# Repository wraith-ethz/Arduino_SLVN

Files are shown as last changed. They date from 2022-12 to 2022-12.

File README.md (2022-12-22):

# Arduino_SLVN
Board for Arduino MKRZero with various buttons / LEDs etc. to learn programming for young children

## Setup

### Assembly
 * Assemble the board according to the file `THT Assembly Drawing.pdf` in the repository under `PCB/Assembly/`
 * The 8x8 Bi-Color LED Matrix from Adafruit can be assembled according to [this link](https://learn.adafruit.com/adafruit-led-backpack/bi-color-8x8-matrix-assembly)

### Installing the Software
 * Download Arduino IDE from [here](https://www.arduino.cc/en/software) and install it
 * Configure Arduino IDE:
  * [libraries](https://docs.arduino.cc/software/ide-v2/tutorials/ide-v2-installing-a-library): install `Adafruit LED Backpack` and `Adafruit GFX` (they are used for the 8x8 matrix)
  * [boards](https://docs.arduino.cc/software/ide-v2/tutorials/ide-v2-board-manager): install `Arduino SAMD Bards` (supports the used Arduino MKRZero board / SAMD21 / ARM Cortex-M0 core)

### Arduino Blocks
 *  go to [ArduinoBlocks.com](http://www.arduinoblocks.com/), create a login

## Workflow
 * create your awesome code on ArduinoBlocks (examples are in the repository folder `/ArduinoBlocks_Examples/`)
  * Use the `MEGA 2560` as project type
  * give it a name, and start coding
 * Connect the board to the PC
 * Start Arduino IDE and create a new sketch (make sure that you have selected the MKRZero as board and the correct COM port)
 * in ArduinoBlocks, go to `Blocks->View Code`
 * Press the `Copy` button
 * Paste it in the Arduino IDE and upload the sketch
 * The Board should now do what you want
 * Enjoy :)

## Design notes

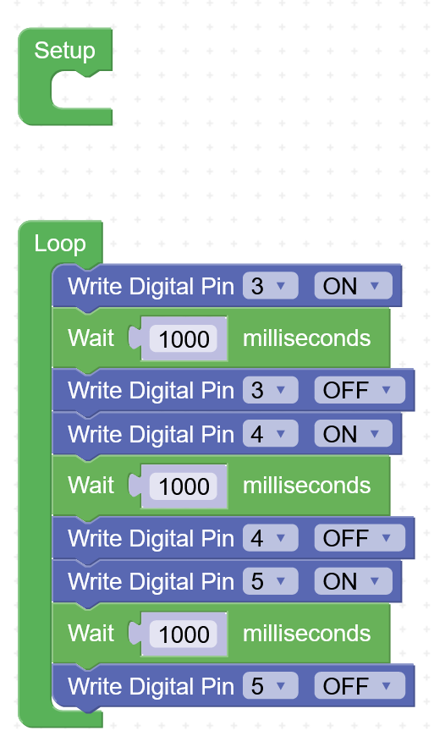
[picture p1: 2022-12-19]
ArduinoBlocks_Examples/RunningLight.png

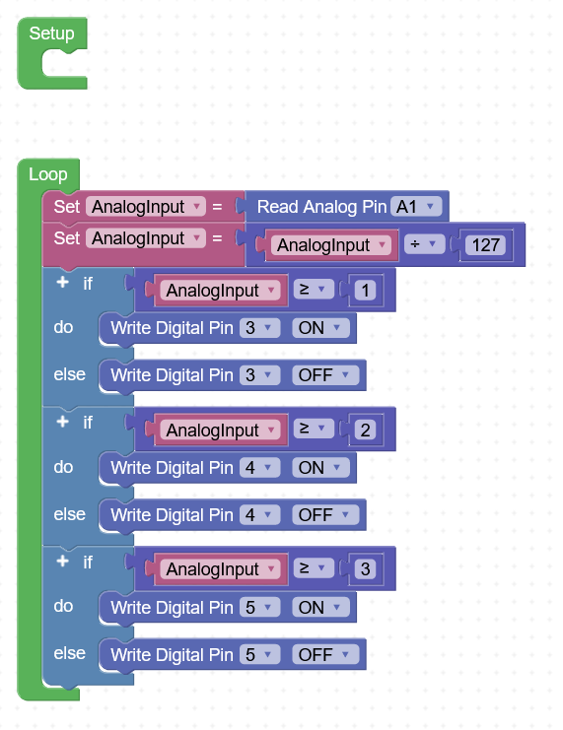
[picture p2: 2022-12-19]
ArduinoBlocks_Examples/AnalogInLED.png

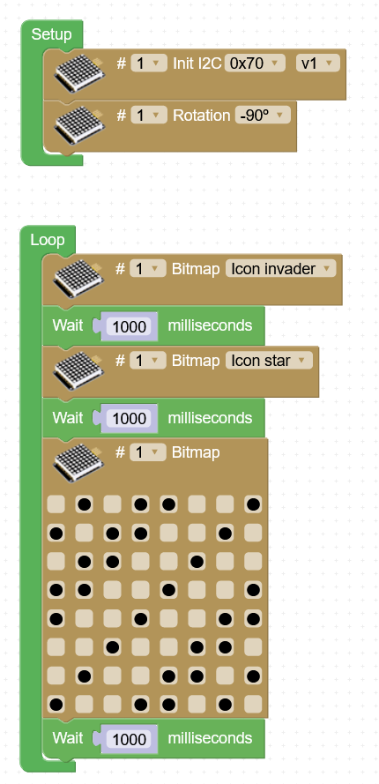
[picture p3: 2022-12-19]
ArduinoBlocks_Examples/8x8Matrix.png

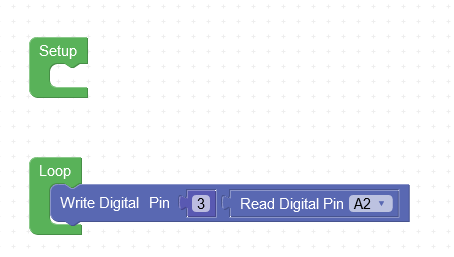
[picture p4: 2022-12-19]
ArduinoBlocks_Examples/InputSwitchToLed.png

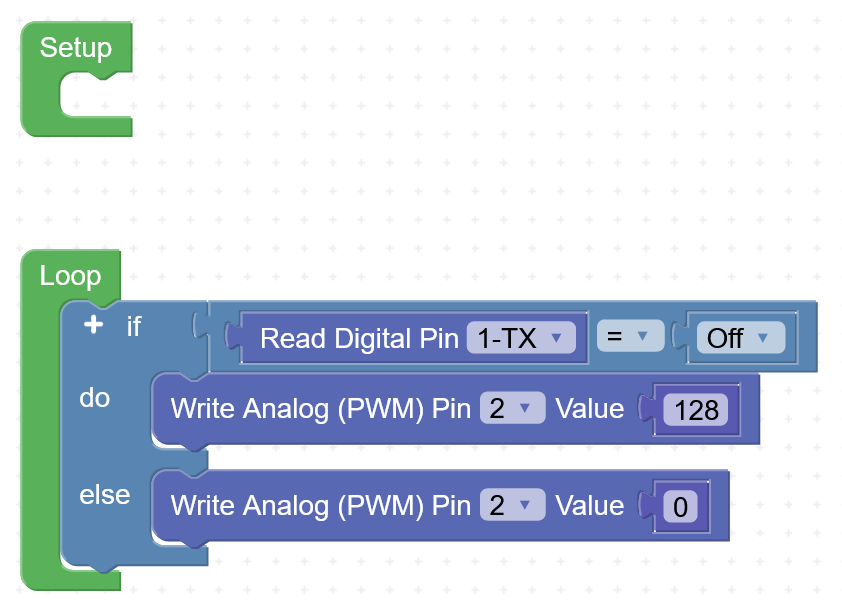
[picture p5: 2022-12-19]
ArduinoBlocks_Examples/BuzzerButton.png

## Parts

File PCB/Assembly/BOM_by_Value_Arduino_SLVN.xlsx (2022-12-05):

Designator | Quantity | Description | Manufacturer | Manufacturer Part Number | Supplier | Supplier Part Number
C1, C2, C3_0, C3_1, C3_2, C3_3, C3_4, C3_5, C3_6, C3_7 | 10 | CERCAP 1n 100V 1% NP0/C0G 0603 | KEMET | C0603C102F1GAC7867 | Digi-Key | 399-17967-1-ND
D1_0, D1_1, D1_2, D1_3, D1_4, D1_5, D1_6, D1_7 | 8 | LED RED 30mA 2V 3x3.4mm | OSRAM Opto Semiconductors Inc. | LS T676-R1S1-1-Z | Digi-Key | 475-2683-1-ND
J1, J2 | 2 | CONN Female 1x14 2.54mm Straight THT 2.54x35.6mm | Sullins Connector Solutions | PPTC141LFBN-RC | Digi-Key | S7012-ND
J3 | 1 | CONN Female 1x4 2.54mm Straight THT 2.54x10.16mm | Sullins Connector Solutions | PPTC041LFBN-RC | Digi-Key | S7002-ND
Q1_0, Q1_1, Q1_2, Q1_3, Q1_4, Q1_5, Q1_6, Q1_7, Q2, Q3 | 10 | MOSFET N 0.2A 50V SOT323 | Diodes Incorporated | BSS138W-7-F | Digi-Key | BSS138W-FDICT-ND
R1, R4_0, R4_1, R4_2, R4_3, R4_4, R4_5, R4_6, R4_7, R7_0, R7_1, R7_2, R7_3, R7_4, R7_5, R7_6, R7_7, R8, R9 | 19 | RES 10K 100mW 1% 0603 | YAEGO | RC0603FR-0710KL | Digi-Key | 311-10.0KHRCT-ND
R2, R5_0, R5_1, R5_2, R5_3, R5_4, R5_5, R5_6, R5_7, R6_0, R6_1, R6_2, R6_3, R6_4, R6_5, R6_6, R6_7 | 17 | RES 150R 100mW 1% 0603 | YAEGO | RC0603FR-07150RL | Digi-Key | 311-150HRCT-ND
R3 | 1 | POTENTIOMETER 10K 50mW 20% 11x9.7mm | Bourns Inc. | PTV09A-4020S-B103 | Digi-Key | PTV09A-4020S-B103-ND
S1 | 1 | BUTTON SPST 12V 0.05A 7.4x7.4mm | E-Switch | TL6120CF300QG | Digi-Key | EG4355CT-ND
S2_0, S2_1, S2_2, S2_3, S2_4, S2_5, S2_6, S2_7 | 8 | SWITCH SPDT 12V 0.1A 4.3x8.6mm | C&K | OS102011MS2QN1 | Digi-Key | CKN9565-ND
XTAL1 | 1 | PASSIVE PIEZO_BUZZER 12.6x7.8mm | TDK Corporation | PS1240P02BT | Digi-Key | 445-2525-1-ND

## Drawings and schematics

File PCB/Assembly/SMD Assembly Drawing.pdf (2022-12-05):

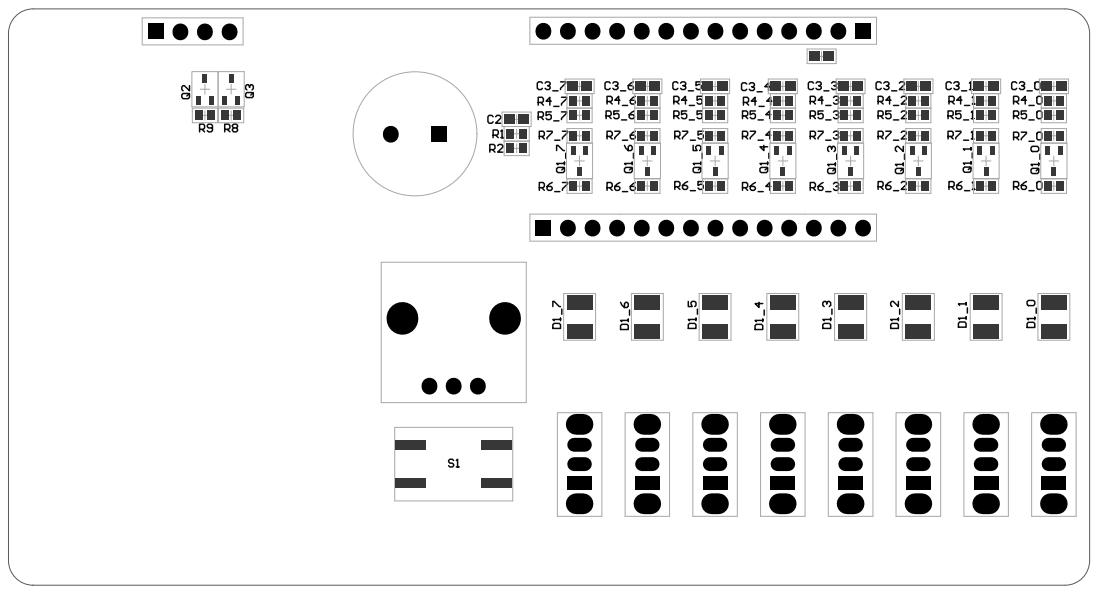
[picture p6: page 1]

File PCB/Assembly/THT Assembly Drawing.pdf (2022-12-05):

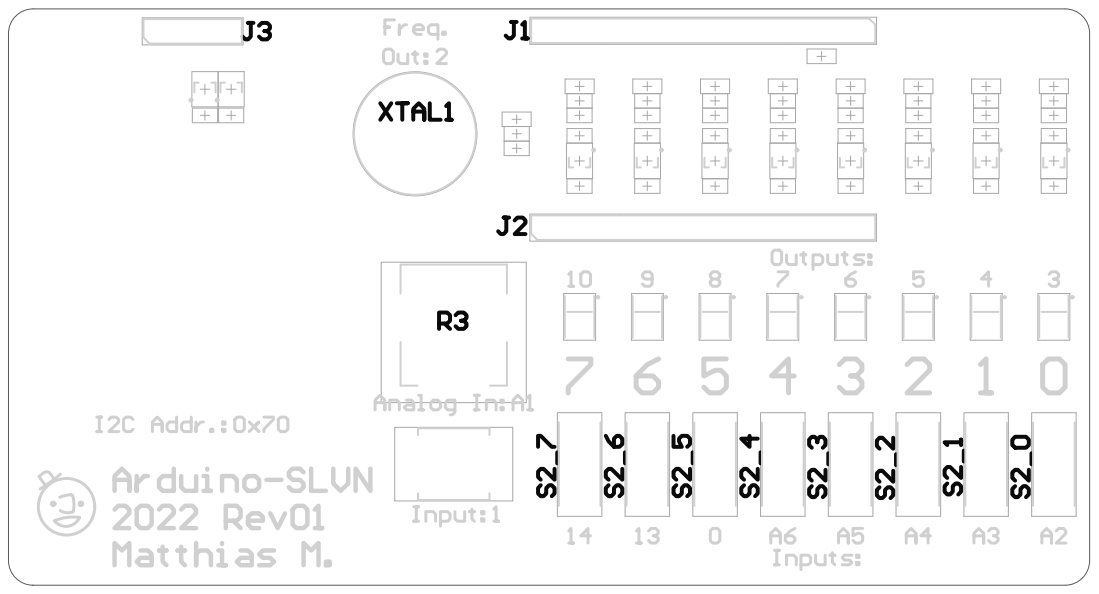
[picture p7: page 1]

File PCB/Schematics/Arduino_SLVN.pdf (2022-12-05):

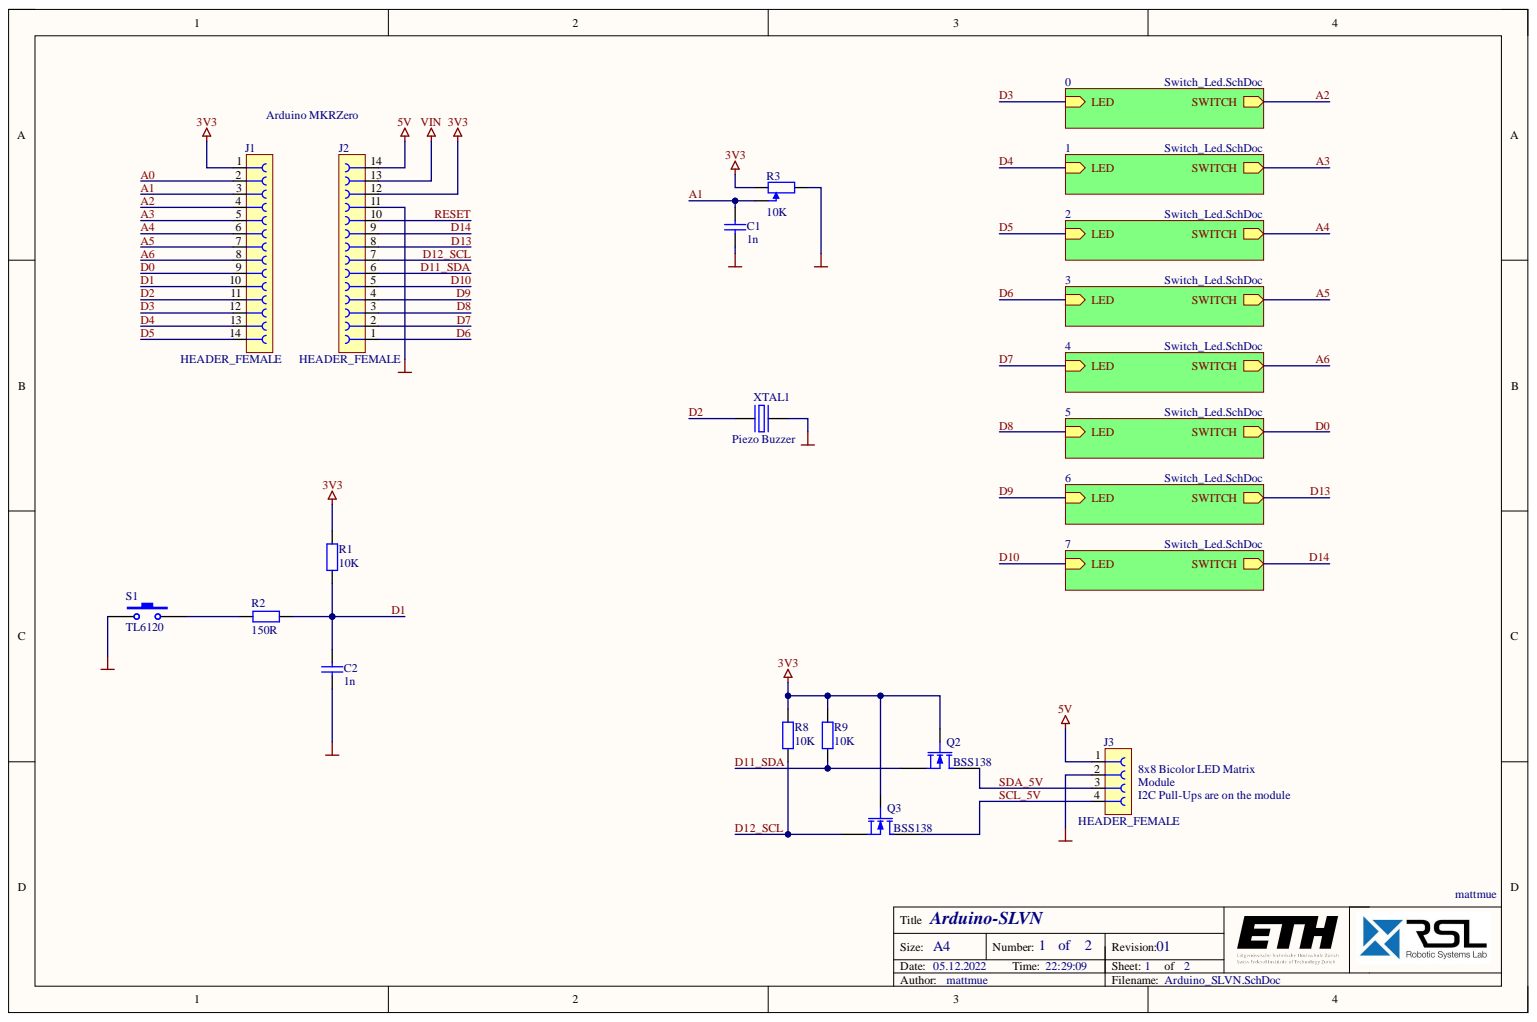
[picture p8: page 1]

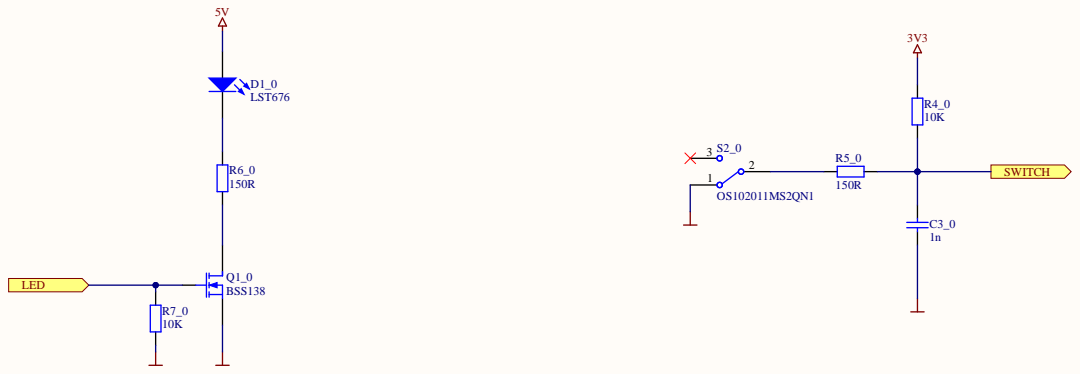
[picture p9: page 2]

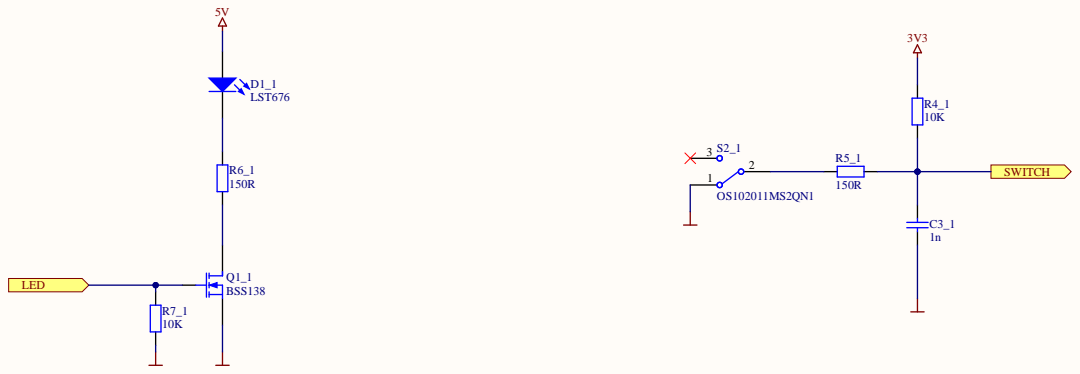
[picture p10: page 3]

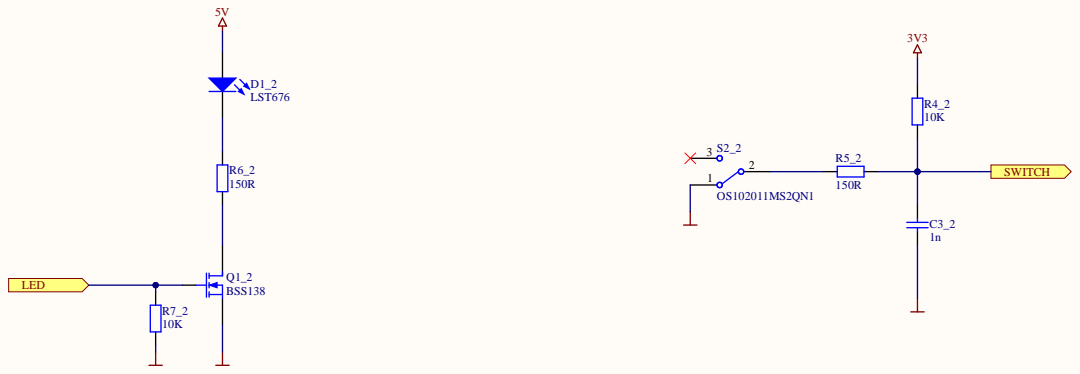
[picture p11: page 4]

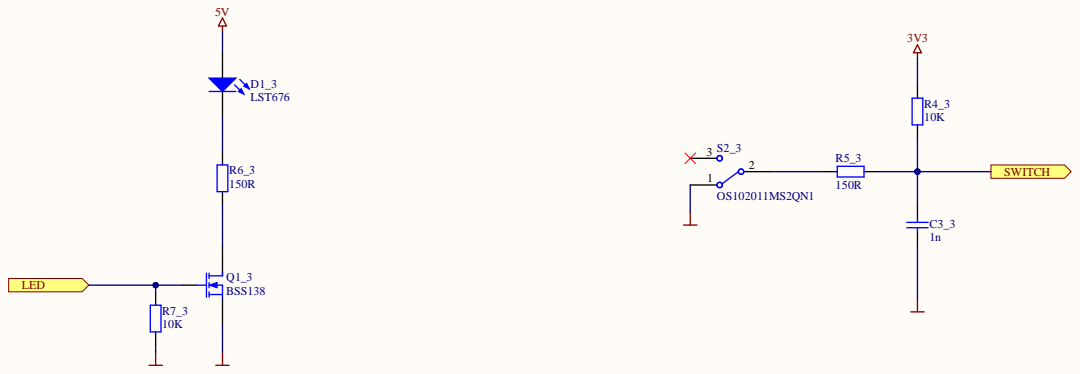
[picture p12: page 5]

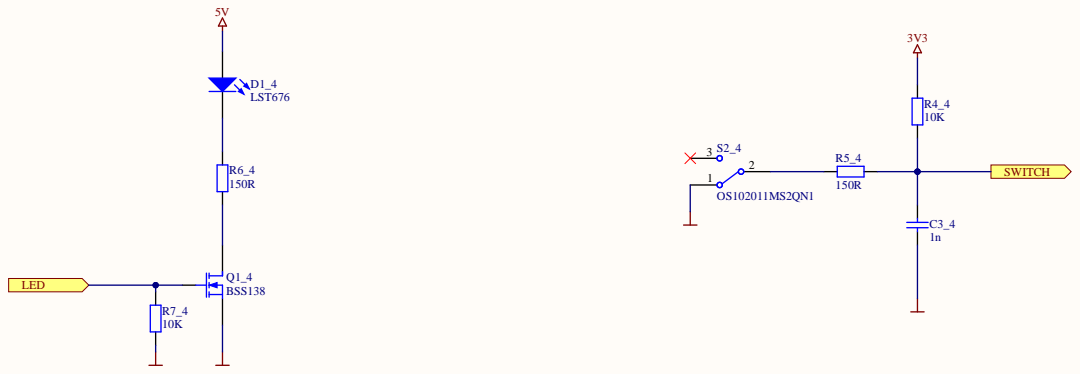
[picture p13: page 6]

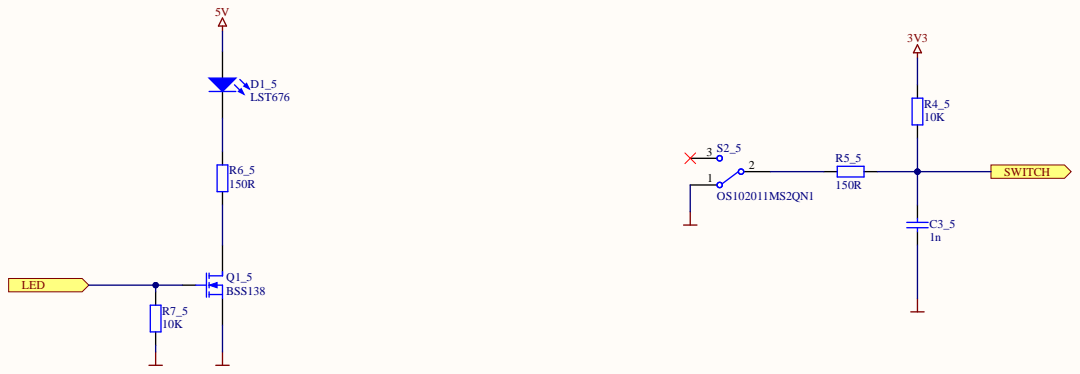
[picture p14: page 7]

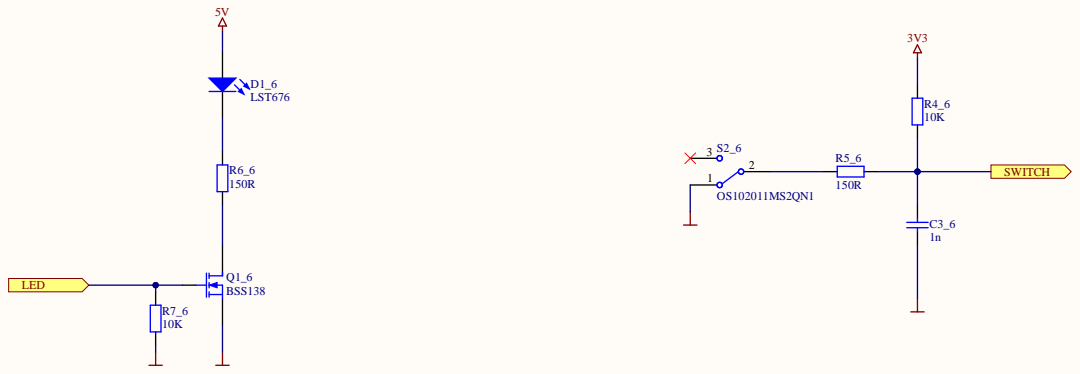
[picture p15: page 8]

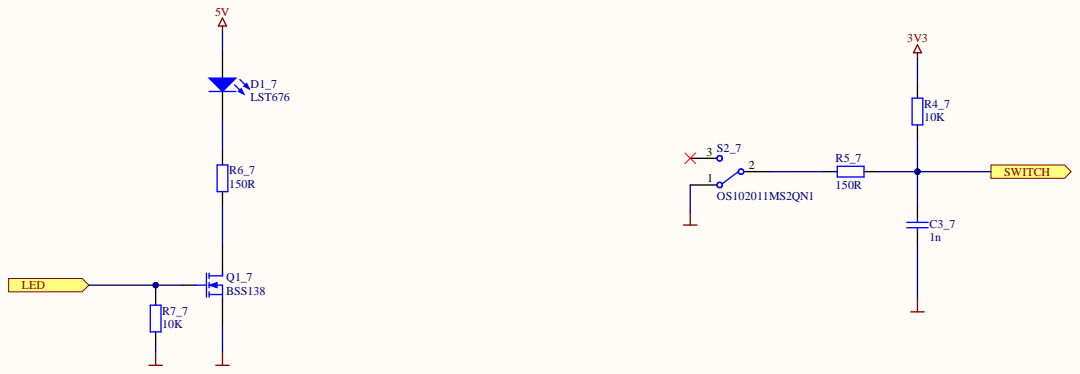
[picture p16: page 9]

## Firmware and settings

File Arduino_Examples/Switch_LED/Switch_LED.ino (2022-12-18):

void setup() {
  // configure all LEDs as outputs
  pinMode(3, OUTPUT);   // set pin 3 as output, for LED 0
  pinMode(4, OUTPUT);   // set pin 4 as output, for LED 1
  pinMode(5, OUTPUT);   // set pin 5 as output, for LED 2
  pinMode(6, OUTPUT);   // set pin 6 as output, for LED 3
  pinMode(7, OUTPUT);   // set pin 7 as output, for LED 4
  pinMode(8, OUTPUT);   // set pin 8 as output, for LED 5
  pinMode(9, OUTPUT);   // set pin 9 as output, for LED 6
  pinMode(10, OUTPUT);   // set pin 10 as output, for LED 7

  // Configure all switches as inputs
  pinMode(A2, INPUT);   // set pin A2 as input, for switch 0
  pinMode(A3, INPUT);   // set pin A3 as input, for switch 1
  pinMode(A4, INPUT);   // set pin A4 as input, for switch 2
  pinMode(A5, INPUT);   // set pin A5 as input, for switch 3
  pinMode(A6, INPUT);   // set pin A6 as input, for switch 4
  pinMode(0, INPUT);   // set pin 0 as input, for switch 5
  pinMode(13, INPUT);   // set pin 13 as input, for switch 6
  pinMode(14, INPUT);   // set pin 14 as input, for switch 7
}

void loop() {
  // check if a switch is set (upper position), if so, enable the LED, else disable it
  
  if( digitalRead(A2) == HIGH){
    digitalWrite(3, HIGH);
  }
  else{
    digitalWrite(3, LOW);
  }

  if( digitalRead(A3) == HIGH){
    digitalWrite(4, HIGH);
  }
  else{
    digitalWrite(4, LOW);
  }

  if( digitalRead(A4) == HIGH){
    digitalWrite(5, HIGH);
  }
  else{
    digitalWrite(5, LOW);
  }

  if( digitalRead(A5) == HIGH){
    digitalWrite(6, HIGH);
  }
  else{
    digitalWrite(6, LOW);
  }

  if( digitalRead(A6) == HIGH){
    digitalWrite(7, HIGH);
  }
  else{
    digitalWrite(7, LOW);
  }

  if( digitalRead(0) == HIGH){
    digitalWrite(8, HIGH);
  }
  else{
    digitalWrite(8, LOW);
  }

  if( digitalRead(13) == HIGH){
    digitalWrite(9, HIGH);
  }
  else{
    digitalWrite(9, LOW);
  }

  if( digitalRead(14) == HIGH){
    digitalWrite(10, HIGH);
  }
  else{
    digitalWrite(10, LOW);
  }
}

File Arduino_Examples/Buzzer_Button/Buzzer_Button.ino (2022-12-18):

void setup() {
  // initialize buzzer (pin 2) as output
  pinMode(2, OUTPUT);

  // initialize button (pin 1) as input
  pinMode(1, INPUT);
}

void loop() {
  // check if button is pressed write a square wave out, if not then not
  if(digitalRead(1) == LOW){
    // write it as ananalog output with 50% duty cycle
    analogWrite(2, 128);
  }
  else{
    analogWrite(2, 0);
  }

  // wait 5ms
  delay(5);
}

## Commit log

2022-11-19 first draft, only mkrzero placed correctly in schematic
    [Arduino_SLVN.PcbDoc, Arduino_SLVN.PrjPcb, Arduino_SLVN.SchDoc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]
2022-11-20 finished schematics, ready for layout
    [Arduino_SLVN.SchDoc]
2022-11-21 placing finished, ready for routing
    [Arduino_SLVN.SchDoc]
2022-11-23 REV01 design finished, BOM & Schematic & Assembly description needed
    [Arduino_SLVN.PrjPcb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]
2022-12-05 created assembly documents
    [Arduino_SLVN.PrjPcb, Arduino_SLVN.SchDoc, BOM_by_Value_Arduino_SLVN.xlsx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]
2022-12-19 added some examples for ArduinoBlocks
